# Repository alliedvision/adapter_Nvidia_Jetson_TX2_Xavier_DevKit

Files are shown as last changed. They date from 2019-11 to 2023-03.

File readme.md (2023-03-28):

# Allied Vision CSI-2 Adapter Board for Nvidia Jetson TX2  Xavier Dev Kit

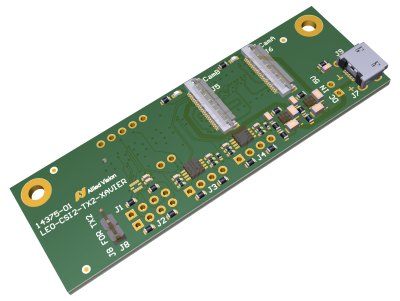
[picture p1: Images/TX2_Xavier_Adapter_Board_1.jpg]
nvidia_TX2_Xavier_adapter

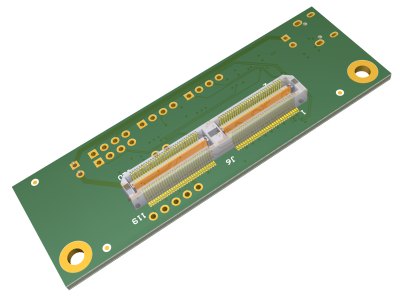
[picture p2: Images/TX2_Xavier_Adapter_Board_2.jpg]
nvidia_TX2_Xavier_adapter


This repository contains open hardware design files for an adapter board supporting the Allied Vision Alvium CSI-2 camera pinout to NVidias TX2 and Xavier Development kit CSI-2 connector compatible devices, created by Allied Vision.
The board allows the user to interface with two Alvium MIPI CSI-2 compatible cameras over a Flexible Flat Cable (FFC) connector.

You can also purchase the adapter from [Allied Vision](https://www.alliedvision.com/en/products/accessories/interface-connections/#!?cameraInterfacefilter=10) or from our [distributors](https://www.alliedvision.com/en/avt-locations/avt-distributors/).

## Getting Started

These instructions will get you a copy of the design files to make your own adapter boards for development and testing purposes. 
The board can be produced and assembled using the provided design files. Please take a look at the mechanical layers for more information regarding the PCB stackup recommended for fabrication. 

See our [accessories webpage](https://www.alliedvision.com/en/products/accessories/interface-connections/#!?cameraInterfacefilter=10) and the [Alvium CSI-2 download webpage](https://www.alliedvision.com/en/support/technical-documentation/alvium-csi-2-documentation/) for more information.

### Prerequisites

* A running installation of Altium.
* A PCB producer & PCBA manufacturer or some soldering skills.
* One of the supported embedded boards :
	* Nvidia Jetson TX2 Developer Kit 	
	* Nvidia Jetson AGX Xavier Developer Kit
* One or two supported MIPI CSI-2 FPC cable
	* Allied Vision part numbers #12316, 12317, 12318
* [One or two Allied Vision Alvium CSI-2 camera](https://www.alliedvision.com/en/products/embedded-vision-cameras.html)

### Installing

Open the *CSI2-TX2-XAVIER_Rev01.PrjPcb* project file in your Altium environment.

## Built With

* [Altium Designer 19](https://www.altium.com/altium-designer/de)
 
## License

This project is licensed under the MIT License - see the [LICENSE](LICENSE) file for details

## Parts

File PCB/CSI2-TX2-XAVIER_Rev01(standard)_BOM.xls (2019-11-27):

 | Bill of Materials | CSI2-TX2-XAVIER_Rev01
 | Project : | CSI2-TX2-XAVIER
 | PCBA : |  | Revision : | 01
 | PCB : |  | Revision : | 01
 | Variant : | standard
 | Schematic : | CSI2-TX2-XAVIER_Rev01 | Schematic.pdf
 | Placement : | CSI2-TX2-XAVIER_Rev01 | Overlay.pdf
 | Report Date : | 26.11.2019 | 15:47
 | Alternative Parts :
Quantity | Designator | Comment | Footprint | Description | Manufacturer | Manufacturer Part Number | KHK Part Number
4 | C1, C2, C3, C5 | 100n | C-0402_0.55 | Capacitor Ceramic SMD/0402/16V/X7R/10% | several | several | K8340114
2 | C4, C6 | 100p | C-0402_0.55 | Capacitor Ceramic SMD/0402/50V/X7R/10% | several | several | K8340145
2 | C7, C10 | 100n | C-0603_1.0 | Capacitor Ceramic SMD/0603/50V/X7R/10% | several | several | K8340023
4 | C8, C9, C11, C12 | 10u | C-0805_1.4 | Capacitor Ceramic SMD/0805/16V/X5R/10% | several | several | K8340151
1 | C13 | NL | C-0603_1.0 | Capacitor Ceramic SMD/0603/50V/X7R/10% | several | several
2 | D1, D2 | GREEN | D-0603-LED | Chip LED green 430mcd | Würth | 150060GS75000 | 8172
2 | D3, D4 | ESD9B5.0ST5G | D-SOD923 | DIODE TVS; 400W; 5.8-7.8V; BIDIRECT | ON Semiconductor | ESD9B5.0ST5G | 7250
4 | J1, J2, J3, J4 | NL | CON 1x4 RM2.54 | Stiftleiste; 1x4; 2.54mm; gerade | Harwin | M20-999 0445
2 | J5, J6 | CON FFC22_Inverted | J-FH55-22S-0.5SH - Inverted Pins | FFC Connector 0.5mm shielded | Hirose | FH55-22S-0.5SH | 10357
1 | J7 | NL | CON 1x2 RM2.54 | Stiftleiste; 1x2; 2.54mm; gerade | fischer elektronik | SL 11 124 2 G
1 | J8 | CON1x2 | CON 1x2 RM2.54 | Stiftleiste; 1x2; 2.54mm; gerade | fischer elektronik | SL 11 124 2 G | K7600582
1 | J9 | USB 2.0 Typ B 90° | J-629105150521 | Micro USB 2.0 Typ B 90° | WE | 629 105 150 521 | 14360
1 | J10 | QTH-060-01-L-D-A | J-QTH-060-XX-X-D-A | 120pin B2B Header 0.5 pitch 10.27mm Height | SamTec | QTH-060-01-L-D-A | 10657
1 | LA1 | LABEL 7x7mm | PCB LABEL 7x7 | LABEL 7x7mm | several | several
6 | MRK1, MRK2, MRK3, MRK4, MRK5, MRK6 | Marker Single Layer | PCB_Marker_Pad_top | Position Marker for PCBs
1 | PCB1 | 14375-01 |  | PCB ML04 | several | 14375-01 | 14375-01
9 | R1, R2, R3, R4, R7, R8, R15, R16, R27 | 0R0 | R-0603_0.6 | Standard Resistor SMD/0603/1%/100mW/TK200, Standard Resistor SMD/0603/1%/100mW/TK100 | several | several | K8250041
8 | R5, R6, R10, R11, R13, R14, R17, R18 | 2k0 | R-0402_0.4 | Standard Resistor SMD/0402/1%/63mW/TK100 | several | several | K8250311
2 | R9, R20 | 3k3 | R-0603_0.6 | Standard Resistor SMD/0603/1%/100mW/TK100 | several | several | K8250070
2 | R12, R19 | 200k | R-0402_0.4 | Standard Resistor SMD/0402/1%/63mW/TK100 | several | several | K8250280
2 | R21, R24 | NL | R-0603_0.6 | Standard Resistor SMD/0603/1%/100mW/TK200
2 | R22, R25 | 270k | R-0603_0.6 | Standard Resistor SMD/0603/1%/100mW/TK100 | several | several | K8250170
2 | R23, R26 | 51k | R-0603_0.6 | Standard Resistor SMD/0603/1%/100mW/TK100 | several | several | K8250156
1 | U1 | NTB0104GU12,115 | IC-XQFN12_1.7x2x0.5 | IC/LOGIC/Levelshifter;Auto-Dir;Bidirectional;Push-Pull;-40-+125°C/ | NXP | NTB0104GU12,115 | 14383
2 | U2, U3 | PCA9306DCTR | IC-TSSOP8_3.15x4.25x1.3 | IC/LOGIC/LEVELSHIFTER;I2C;AUTO-DIR;1V2-5V/SSOP-8/4.25x3.15x1.3mm | TI | PCA9306DCTR | 9555
2 | U4, U5 | TPS25200DRVT | IC-DFN06_2.0x2.0x0.8 | IC/PWR/LOADSW;2V5-6V5;2A5;0R099/6-WDFN/2x2x0.8mm | Texas Instruments | TPS25200DRVT | 14277

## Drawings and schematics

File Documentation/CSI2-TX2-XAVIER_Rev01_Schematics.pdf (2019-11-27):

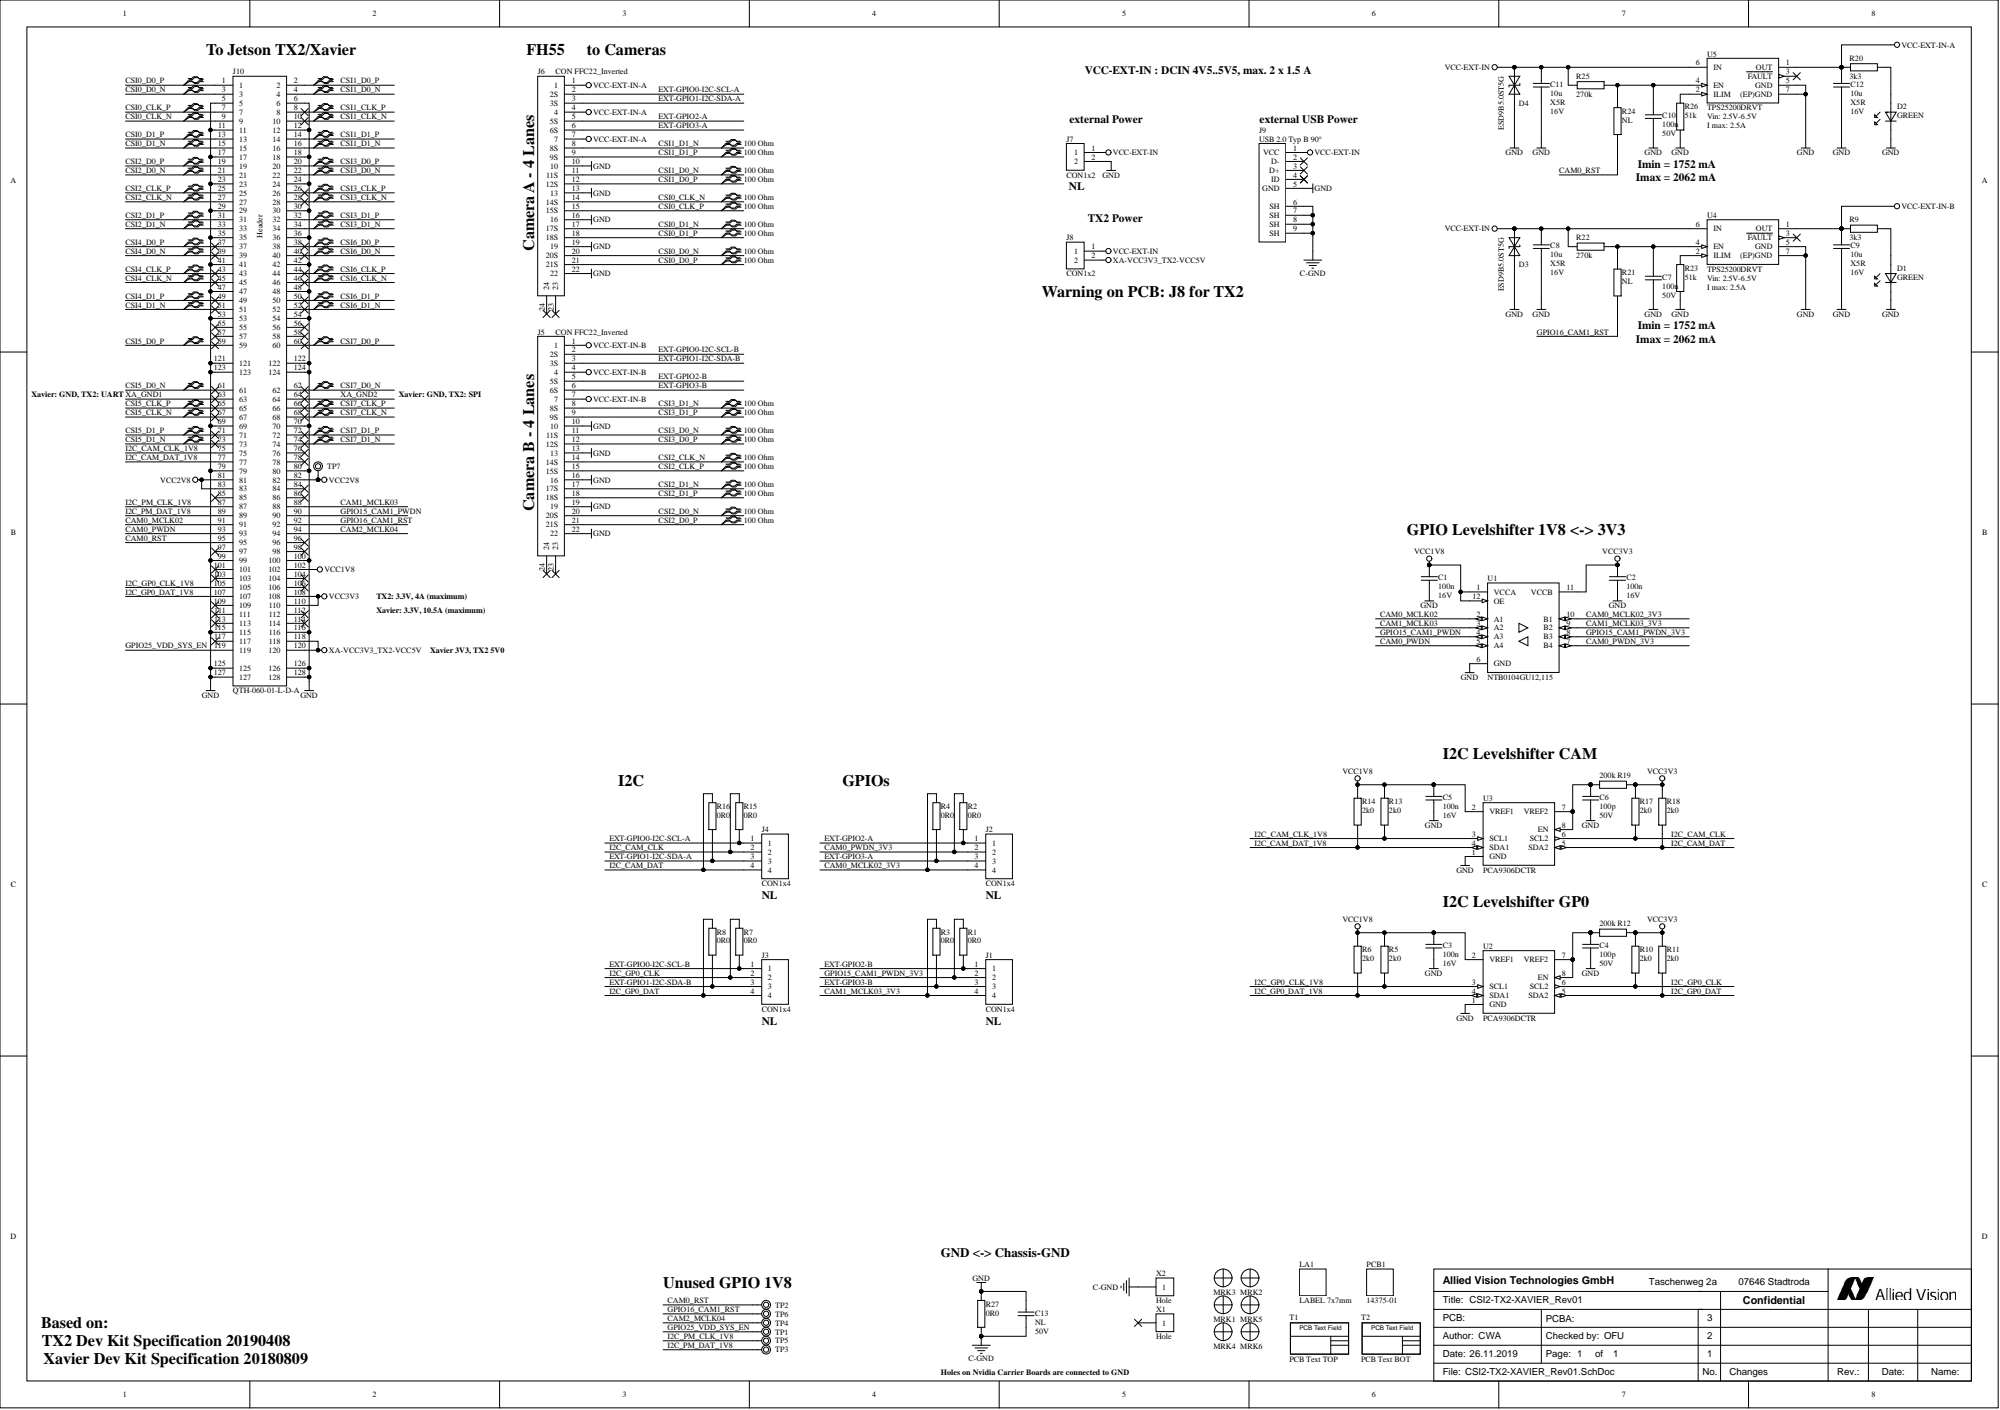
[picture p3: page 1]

VCC-EXT-IN : DCIN 4V5..5V5, max. 2 x 1.5 A

CON1x2
Warning on PCB: J8 for TX2

Allied Vision Technologies GmbH Taschenweg 2a 07646 Stadtroda

Title: CSI2-TX2-XAVIER_Rev01 | Confidential

Based on:
TX2 Dev Kit Specification 20190408
Xavier Dev Kit Specification 20180809

Author: CWA | Checked by: OFU | 2

Date: 26.11.2019 | | 1

Holes on Nvidia Carrier Boards are connected to GND

File: CSI2-TX2-XAVIER_Rev01.SchDoc | | No. | Changes | Rev.: | Date: | Name:

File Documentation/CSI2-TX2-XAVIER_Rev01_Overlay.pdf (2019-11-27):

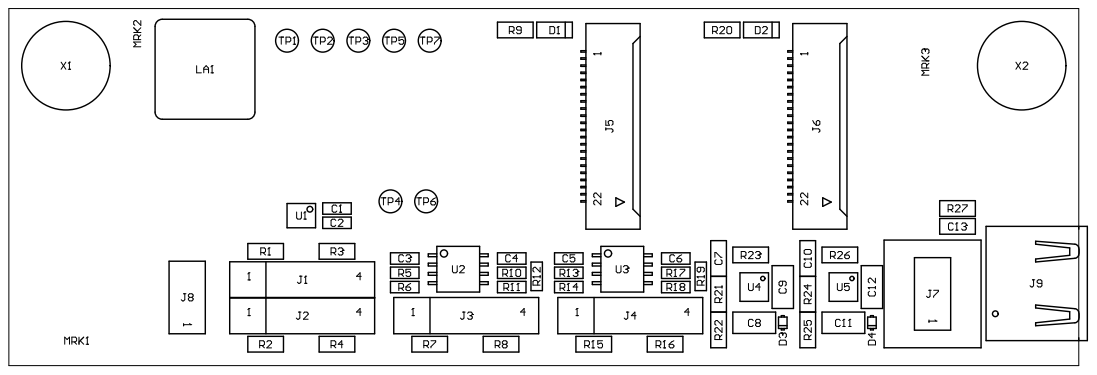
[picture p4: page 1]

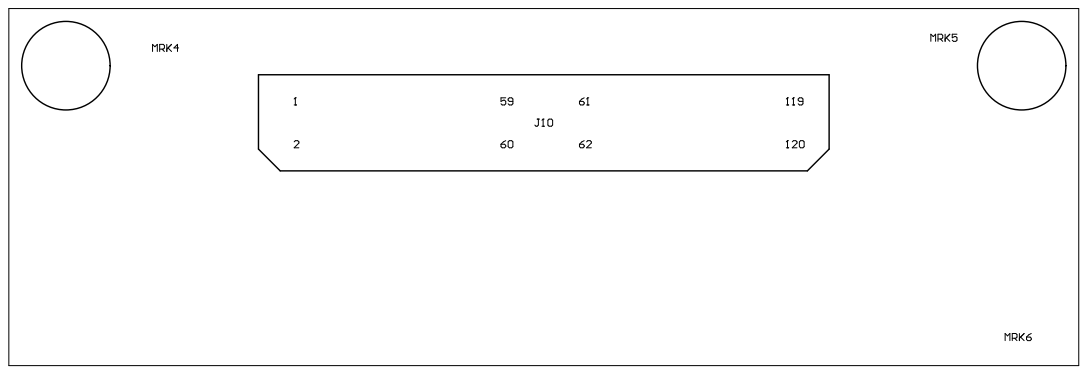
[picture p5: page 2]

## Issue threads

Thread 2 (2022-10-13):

residual voltage on j1/j2 pins 1/3 when trying to use as input gpio

harelhel, 2022-10-13:
manual says to remove resistors R1 R2 R3 R4 in order to use as GPIO
however after removal whenever adapter board is powered (even if not connected to Jeston) GPIO pins have a constant ~2.2V voltage.
this behavior is not affected by setting in software GPIOs to be either input OR output
examples and code from allied vision GitHub repository was used with same results.
cameras work fine with software trigger but with current situation , HW trigger is impossible.
we tried it with several boards and several adapters. does gpio require an additional  pullup/pulldown resistor?

this was tested using a JESTON XAVIER with jetpack 4.6.1/4.6.2/5.0.2 (and as mentioned this behavior was observed when adapter was not connected as well)
2 cameras are allvium 1800 c-040m with
it was also observed when only 1 camera was connected with 12318 cables.
please provide example schematic for connecting to external HW trigger
